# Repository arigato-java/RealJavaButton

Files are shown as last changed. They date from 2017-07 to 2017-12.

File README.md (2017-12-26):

# RealJavaButton v1

JavaButton on the real world.

* 対象年齢: 全年齢 (審査申請準備中)

## Examples

Front(ver 1.0):
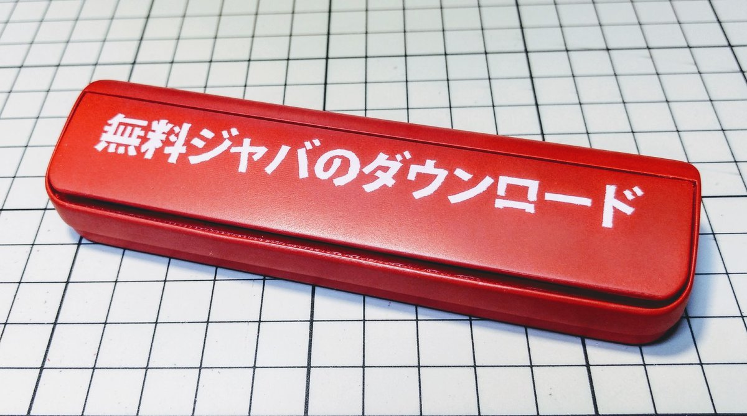
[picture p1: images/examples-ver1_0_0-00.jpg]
ver 1.0.0 front


Back(ver 1.0):
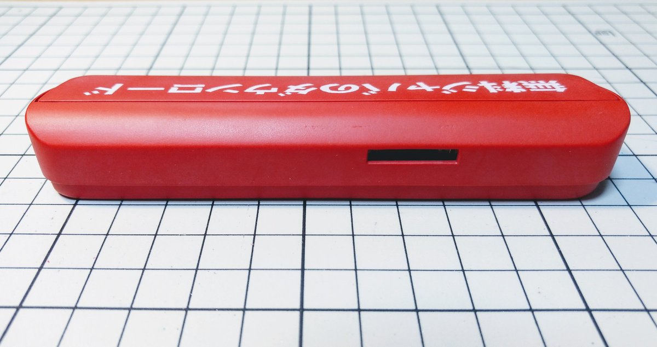
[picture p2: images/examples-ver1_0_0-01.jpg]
ver 1.0.0 back


Bottom(ver 1.0):
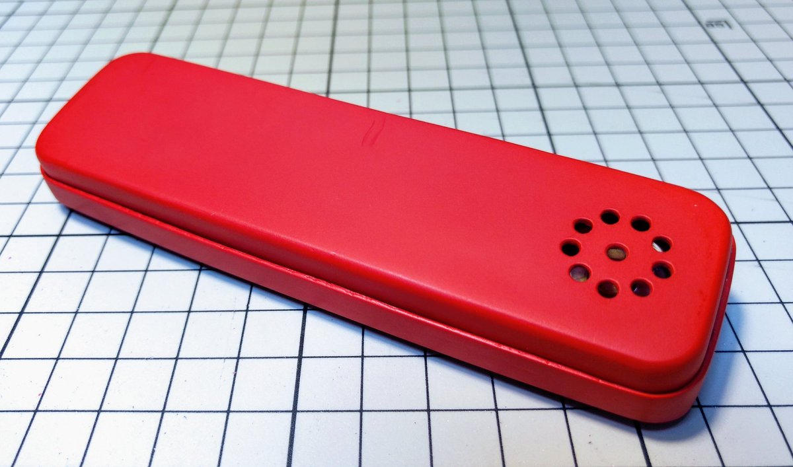
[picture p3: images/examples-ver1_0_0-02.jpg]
ver 1.0.0 bottom


Inside(ver 1.0):
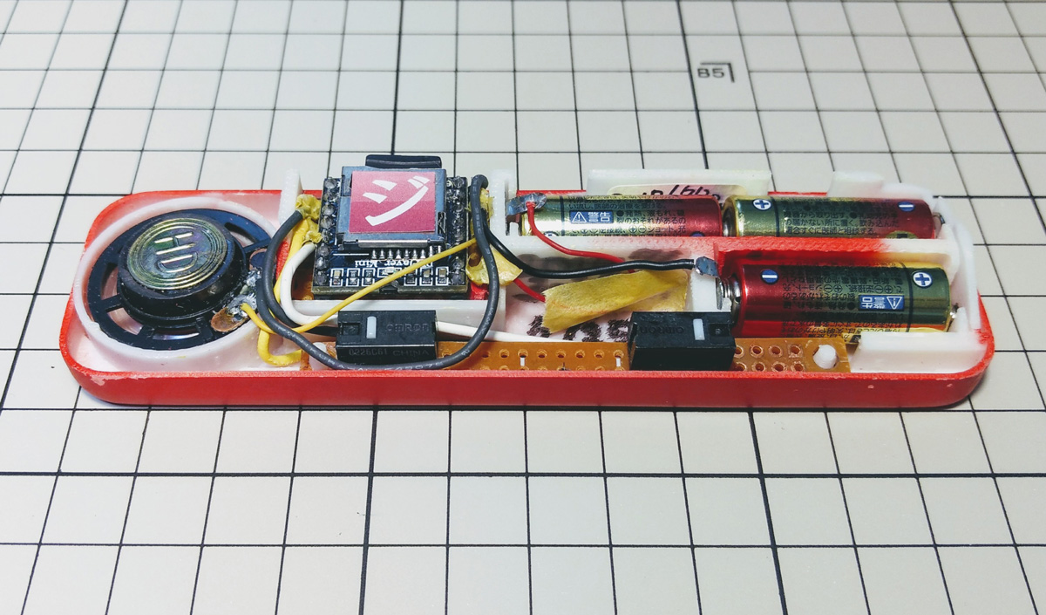
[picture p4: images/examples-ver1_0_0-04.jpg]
ver 1.0.0 inside


## Resources

* For 3D printing:
  * Top Cover Model([STL](./models/case-lid01.stl), [.f3d(Fusion360)](./models/case-lid01.f3d), [online](http://a360.co/2t33CEH))
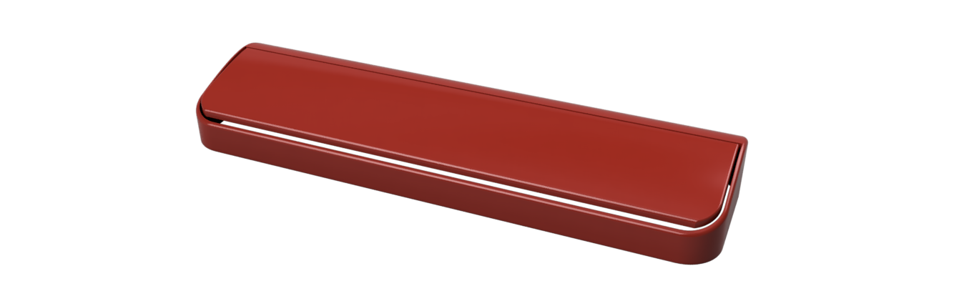
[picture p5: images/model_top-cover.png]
    
  * Bottom Model([STL](./models/case-bottom03.stl), [.f3d(Fusion360)](./models/case-bottom03.f3d), [online](http://a360.co/2umziJ7))
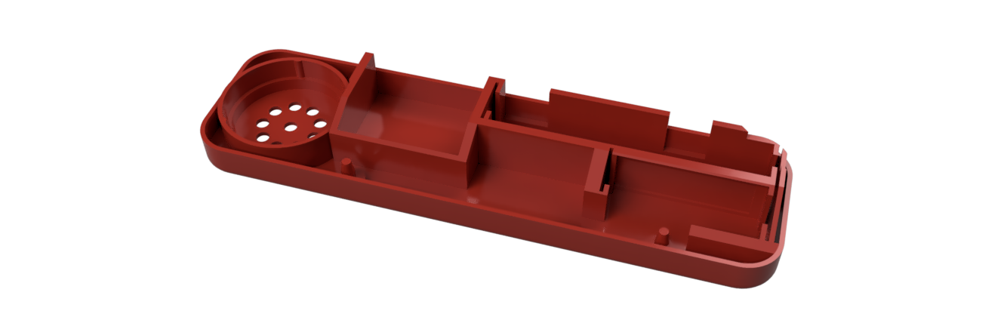
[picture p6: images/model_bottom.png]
    
  * Masking Sheet 印刷用:
    * [PDF](./images/javabutton_label00_170x225mm.pdf)
    * [Illustrator形式(.ai)](./images/javabutton_label00_170x225mm.ai)
    * [同 outline化済(.ai)](./images/javabutton_label00_170x225mm(outline).ai)

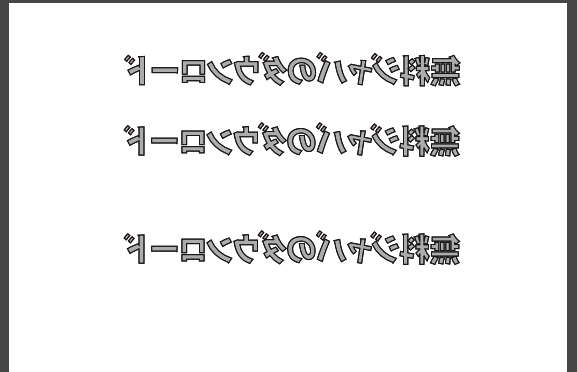
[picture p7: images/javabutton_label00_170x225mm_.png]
For Masking
    

    * (印刷には不要) 元データ:
    [Illustrator形式](./images/javabutton-string-only.ai)
    ([outline化済](./images/javabutton-string-only(outline).ai)))

## Bill of materials

部品リスト

* [FN-M16P Compatible Audio Module](https://www.amazon.co.jp/dp/B01D1D0E7Q/) x1
  ( [datasheet](http://www.trainelectronics.com/Arduino/MP3Sound/TalkingTemperature/FN-M16P%20Embedded%20MP3%20Audio%20Module%20Datasheet.pdf) )

* [OMRON D2FC Compatible Micro Switch](https://www.amazon.co.jp/dp/B00YM2Q178/) x2
* Cut universal board for Micro switch, about 71 x 8.5mm.(スイッチ取り付け用基盤をカットして用意) x1
* 8ohm 0.25w Speaker (⌀27mm)  x1
* Some short wires(短い導線いくつか)
* Battery contact(電池ボックス用金具) それぞれ幅 11mm 以内:
  * プラス側 金具 x1
  * マイナス側 金具 x1
  * プラスマイナス 金具 x1
* Battery: 1.5V N Cell(R1, 単5電池, 12x30.2mm)  x3

参考情報:

* 参考: Audio Module に関して、リンク先での購入は、2つのうち1つは動かない覚悟で。
* 参考: スピーカー取り付け用基板は、 ユニバーサル基盤から切り出した。
* 参考: スピーカーは、100均のおもちゃのピアノから流用。
* 参考: 電池ボックス用金具らは、100均のおもちゃから流用。
* 参考: 単5電池のプラマイは間違えやすく、ショートしやすいので注意。(要改善)

## Schematic

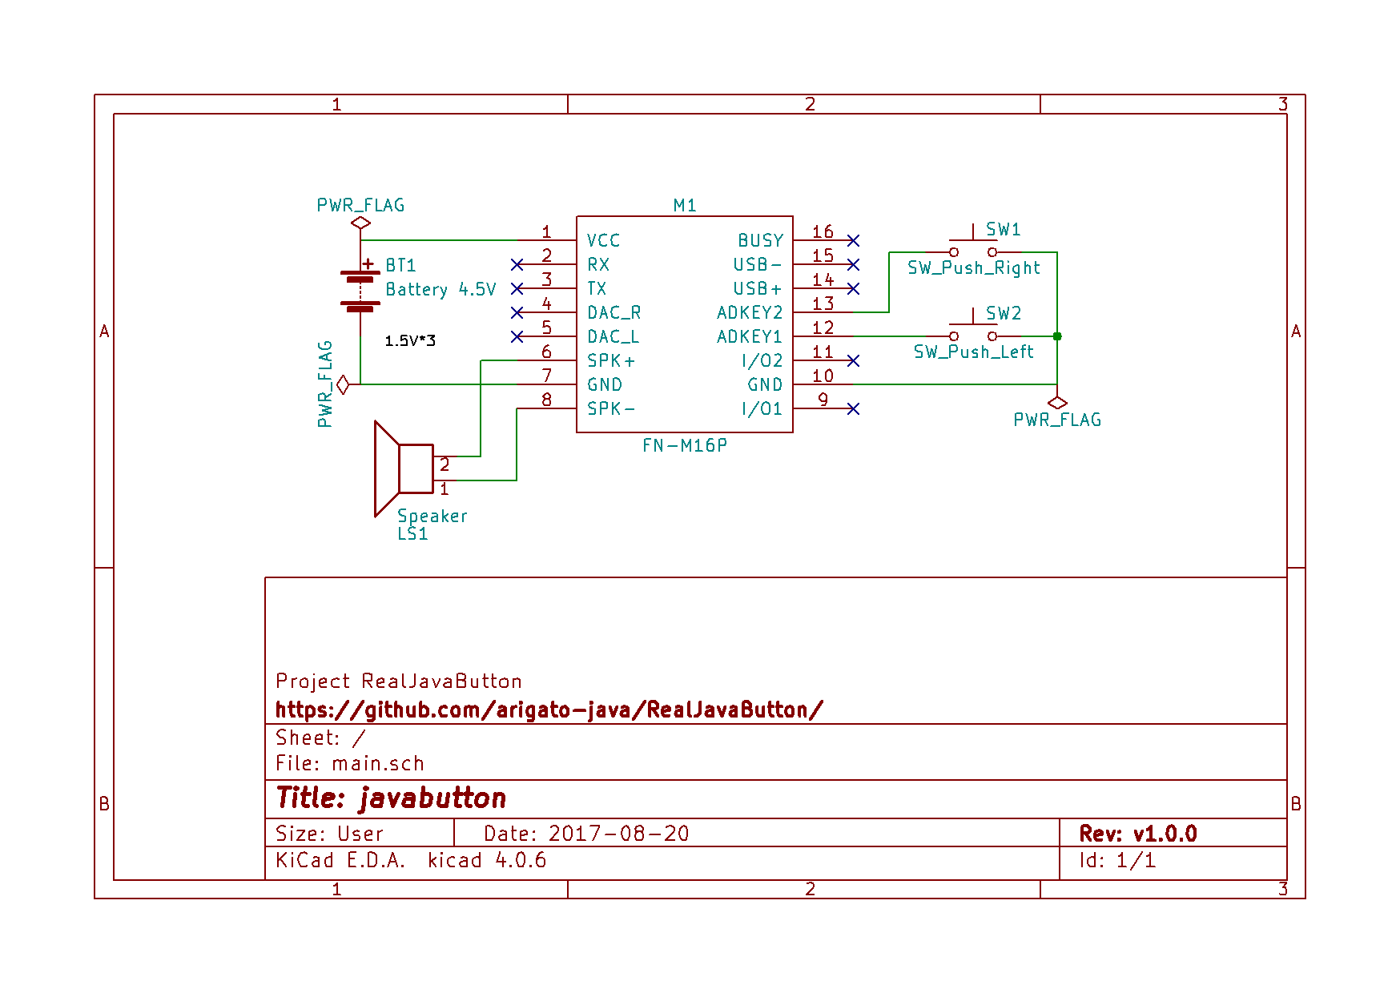
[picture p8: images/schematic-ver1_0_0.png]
ver 1.0.0 回路図


You can open `schematic/main.pro` using `KiCad` v4.x.x , if you want to see/edit those schematics.

## Confirmed environments(確認済み環境)

* For 3D printing
  * Printer: [Qidi Technology Dual Extruder Color 3D Printer / ABS / PLA 1.75mm デュアル押出/色](https://www.amazon.co.jp/dp/B01CRNV038/)
    * FDM Type(Fused deposition modelling, 熱溶解積層法)
    * Nozzle Diameter: ⌀0.4mm
    * Model: 3DF-QD-ABSYW
  * Filament : **ABS** (attached in the printer)
  * Slicer Software: MakerWare 2.4.1.24 (attached in the SD card, configured)
  * Platform Sheet: [3M platform Seat](https://www.amazon.co.jp/dp/B01M11XI4Y)
  * Configurations(see below)
* For painting:
  * 塗料等
    * サーフェサ: [ファインサーフェイサー(ピンク)](https://www.amazon.co.jp/dp/B00BBPUKDA)
    * 赤: [Mr.カラー キャラクターレッド(半光沢)](https://www.amazon.co.jp/dp/B0049FD5CC)
    * 白: [Mr.カラー スプレー S62 つや消しホワイト(つや消し)](https://www.amazon.co.jp/dp/B0049FBLFU)
    * 仕上げ材: [GSIクレオス Mr.トップコート(つや消し)](https://www.amazon.co.jp/dp/B0000WS12C)
  * パテ等
    * [ポリパテ](https://www.amazon.co.jp/dp/B000BMX1BM): 積層をなだらかにするため
    * [ラッカーパテ](https://www.amazon.co.jp/dp/B000R9N5VU): キズ埋めのため
  * [マスキングシール](https://www.amazon.co.jp/dp/B004WBC07Y):

      ジャバ文字の塗装用マスキングシート
  * デザインナイフ, ヘラ, 等々
  * ヤスリ: 320, 800, 1200(いずれも耐水性)
    * (あれば楽) [タイラー](https://www.amazon.co.jp/dp/B0026O9H6G)
      * 元のを剥がし、必要なヤスリを貼って使っている
    * 粉塵が出にくく、目詰まりしにくいため、水研ぎが楽
  * (あれば) 塗装ブース
* Software
  * CAD/CAM: **Autodesk Fusion360**

## Configurations to export from slicer (MakerWare)

Exaples:

* Top cover:

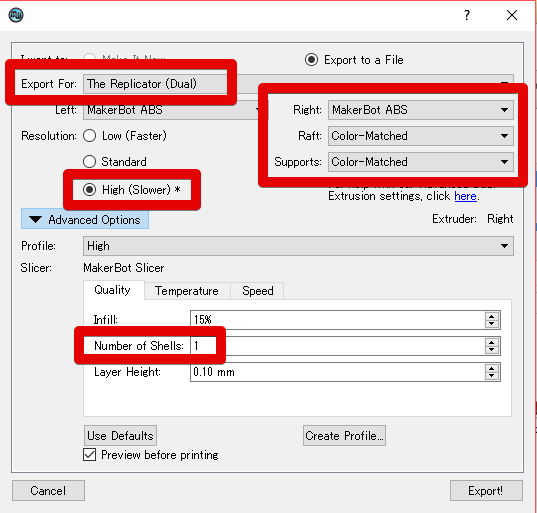
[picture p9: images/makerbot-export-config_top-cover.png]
上ブタ 設定
  

  Preview:

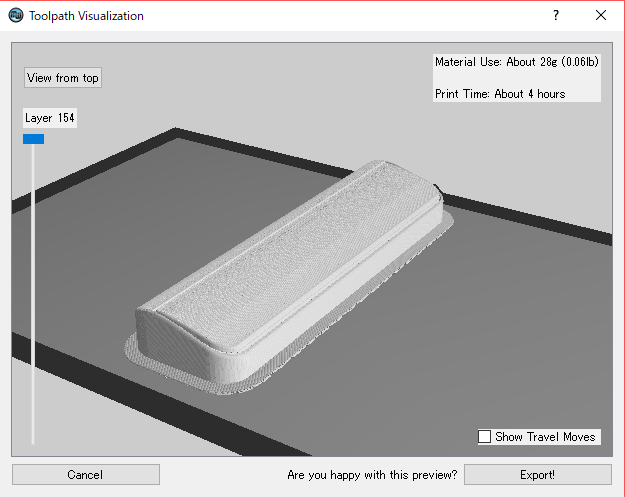
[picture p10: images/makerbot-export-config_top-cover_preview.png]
上ブタ 設定プレビュー
  

* Bottom case:

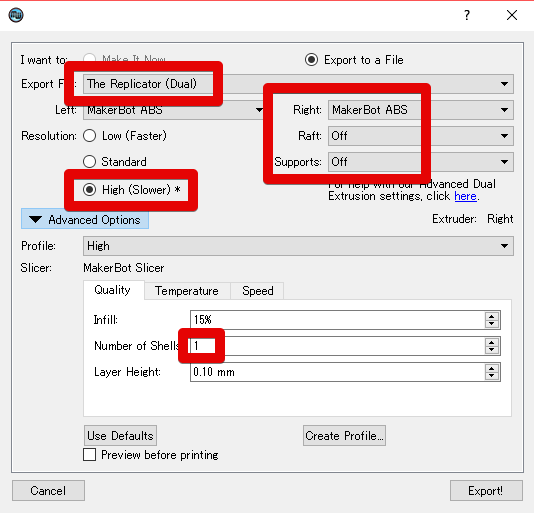
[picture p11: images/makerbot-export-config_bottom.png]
下ケース 設定
  

  Preview:

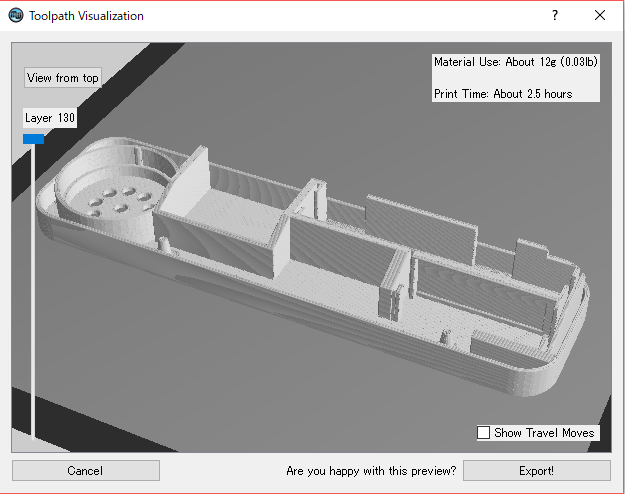
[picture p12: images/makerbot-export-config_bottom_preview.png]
下ケース 設定プレビュー
  

## Appendix: Examples of printing labels

文字塗装の例:

1. マスキングシートの裏に、文字列を印刷する。シートからマスキングを切り抜く。(データは前述)

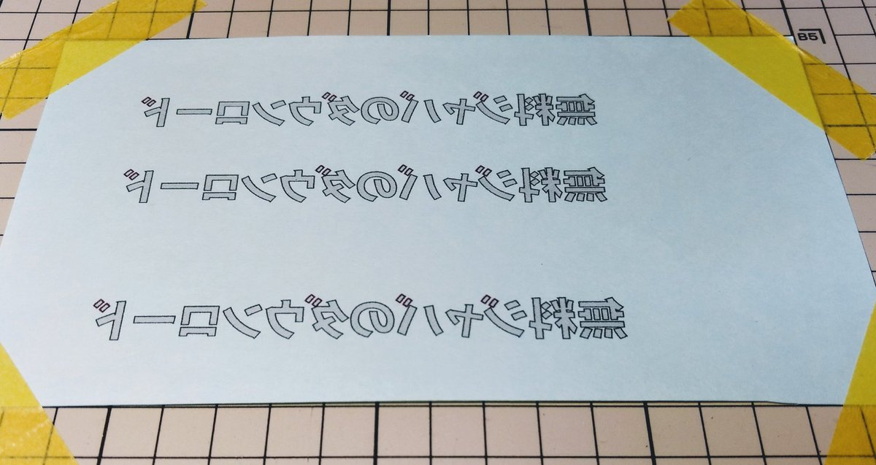
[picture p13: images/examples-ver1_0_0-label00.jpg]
    

1. 塗装済みのジャバボタンに貼る。スプレーされてもいいいように、マスキングシートの周りをマスキングする。(土台の利用は塗装を簡単にするため)

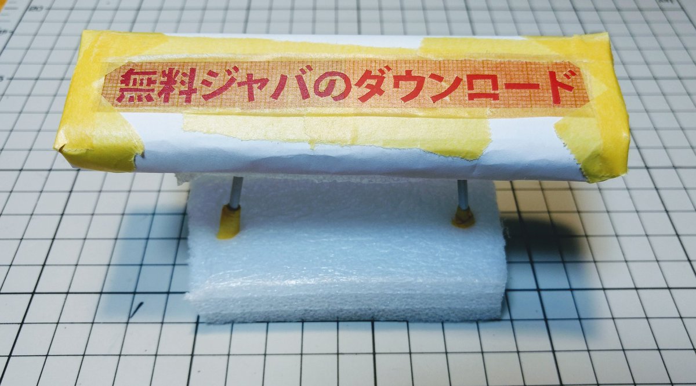
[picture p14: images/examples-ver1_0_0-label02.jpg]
    

1. 二度ほど白スプレーを吹き、乾いたのち仕上げ材を吹き、乾いたら出来上がり

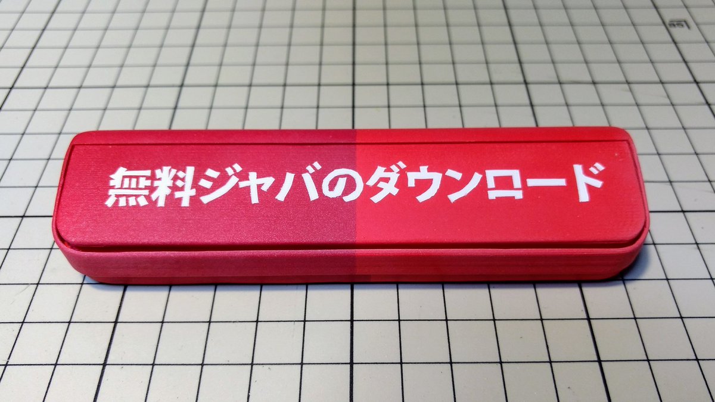
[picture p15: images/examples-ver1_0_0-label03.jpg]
    

    (※写真は試作中のものです)

## License

[Unlicense](./LICENSE)

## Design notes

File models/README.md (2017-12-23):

# About file format

* `*.stl`: General 3D format.
* `*.f3d`: For [Autodesk Fusion 360](https://www.autodesk.com/products/fusion-360/overview)

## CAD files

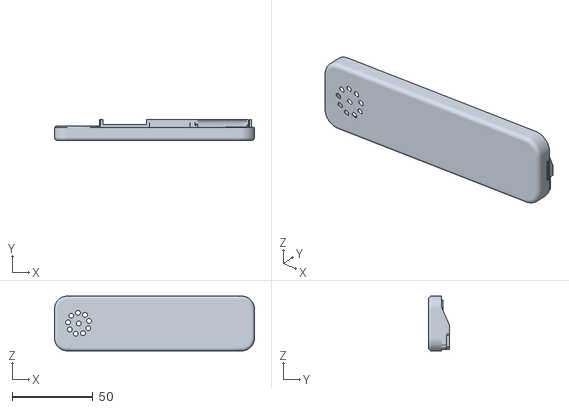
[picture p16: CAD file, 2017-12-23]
models/case-bottom03.stl
124.0 x 13.0 x 34.0

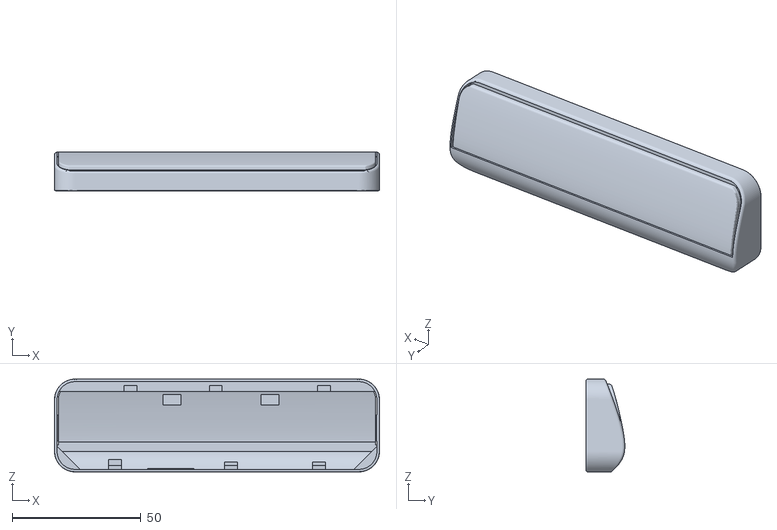
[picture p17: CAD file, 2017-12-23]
models/case-lid01.stl
126.0 x 15.0 x 36.0

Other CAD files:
models/case-bottom03.f3d
models/case-lid01.f3d

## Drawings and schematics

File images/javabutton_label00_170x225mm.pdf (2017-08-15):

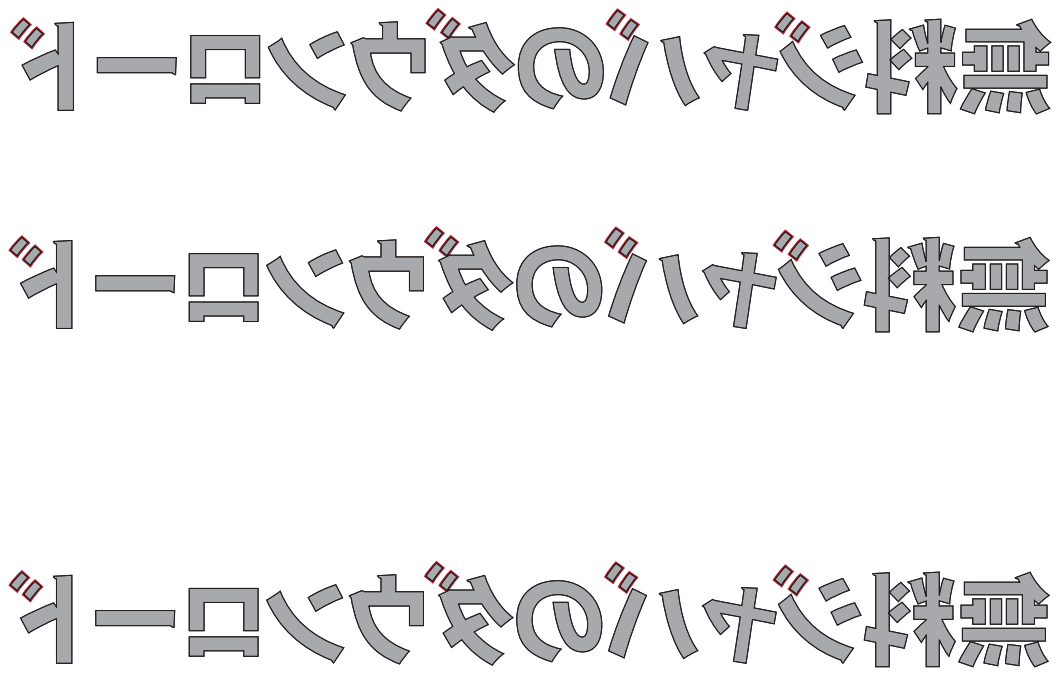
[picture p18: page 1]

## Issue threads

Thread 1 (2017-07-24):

上蓋の構造について

tomari, 2017-07-24:
素人の意見で申し訳ないのですが、上蓋の下半分が動くという構造は、見た目や造形の自由度の面で必ずしも有利と言えないと思っています。

上蓋を完全に一体にして（上蓋全体を押下可能にして）、継ぎ目が見えないような構造を作ることは難しいのですか？

tobynet, 2017-07-27:
元にしたおもちゃが、上ぶたの一部を押下する構造でした。
元は上ぶたは一体型でなかったのですが、一体にして今の形になっています。

現在はほんとに「作ってみた」状態でして、
上ぶた全体を押下可能にする案、アイデアはぜひ欲しいです。
(結果的に今回実現された左右を使ったクリック感は減るかもしれません)

ラフなスケッチなどあるとすごく参考になります。

tobynet, 2017-07-27:
ああっと、今、上ぶたに「切れ目」が入っていますが、そこをふさぎ、
マウスのような形状に、という案でしょうか。

tomari, 2017-07-27:
私の意図してる構造は、Apple Pro Mouseのような、上フタ全体がボタンというものです。
（これです：　https://www.flickr.com/photos/33585243@N04/3128121168 )

tobynet, 2017-07-29:
なるほど。 理解しました。これは目指す方向性と一致しますね。

tomari, 2017-11-19:
ジャバボタンライト：　光るジャバボタン (emissive Javabutton)、 仙人の意向を受け電飾の仕様が追加された。

tobynet, 2017-11-30:
Apple Pro Mouse を、秘密裏にジャックコーナーから入手いたしました。
これはすごい構造ですね。特許ものです。

tobynet, 2017-11-30:
自作キーボードの構造は参考になるやもしれません
ある意味、ジャバボタンというの上部構造は、細いキーボードにでかいキーキャップをかぶせた構造とも言えるわけです

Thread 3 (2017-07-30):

文字列の描写方法の模索

tobynet, 2017-07-30:
## サマリー

ジャバボ表面に文字列を入れる方法について、コスパの高い方法を模索したい。
見栄えよく、低コスト（「お金」と「労力」を減らす)を実現できないか。

## 試した方法の一覧

|                 | 手間 |再利用性|仕上り| 参考リンク |
|-----------------|:----:|:-----:|:----:|-----------|
|ステンシル        |  ◯  |  ◯   |  ×    | |
|マスキングシート   |  ×   | △    |  ◯    | |
|2色成型              | (未評価) | (未評価) | (未評価) | |

## 参考情報

* ステンシル
  * Pros:
    * 再現性は、3Dプリンタに依存
    * 再利用しやすい
  * Cons:
    * 塗装の出来はわるい(画像は後述)
      * 対象物と密着させにくく、塗料がはみ出る
    * 出力と調整の繰り返しが何度か必要。
  * 工程例:
    1. CADでデータを作成
    1. 3Dプリンタにて型を出力
    1. ナイフで型を調整
    1. 対象に貼り付け、塗料を塗る

* マスキングシート
  * Pros:
    * 塗装の出来はわるくない(画像は後述)
  * Cons:
    * 「無料ジャバのダウンロード」の切り抜きに、一時間程度の時間と集中を要する。
    * 再利用しにくい(2,3回が限度か)
    * 出力と調整の繰り返しが何度か必要。
  * 工程例:
    1. Illustlator でデータ作成
    1. インクジェットプリンタを使い、マスキングシートに印字
    1. デザインナイフでシートを切り抜く
    1. 対象にシートを貼り付け、塗料を塗る

* デュアル3Dプリンタによる二色成型:
  * (未評価)

## 参考画像

* ステンシル(?)での実装例
  1. 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
  1. 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
  1. 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
* マスキングシートでの実装例
  1. 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
  1. 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
  1. 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

* TODO: 二色成型

## 他

* 他によい案はないか
* 改善方法はないか

tomari, 2017-07-30:
キーボードでは、２色成形とよばれる方法が使われることがあります。
現在の3D プリンタのワークフローや精度に乗るかは不明ですが、再現性という面では期待が持てそうです。
http://www.yamashita-denki.co.jp/product/plastics/dm/dm02.html

tobynet, 2017-07-30:
ありがとうございます、いい案ですね。

環境さえ用意できれば、再現性の面で大きいのがよいですね。
塗装を各自でやるのは、たいへんですので。。。

* **前提:** 塗装なし
* **データ:** 2色用の3Dデータを用意
* **3Dプリンタ:** デュアルで出力が可能なもの
　* **素材(フィラメント):** 赤白を用意

幸いうちはデュアルの機種なので、赤白のフィラメントを用意できれば試すことができます。

設計が必要なのと、ワークフローが変わるため、今回のプロトタイプ以降に試してみたいです。

tomari, 2017-07-30:
その後ジャバ社の事務所でブレストをやっていました。その中で、インクジェット用の透明なステッカーシートを用いて文字を貼ってしまうというアイデアが出て、これは一考に値するかと思います。

tobynet, 2017-07-30:
シールいいですね。

表面を滑らかにしさえすれば、貼って終わりにできます。

tobynet, 2017-07-30:
現行の家庭用インクジェットプリンタは白色を出力できないため、
（原作に忠実に再現するならば）白いステッカーなどで代用する必要があることが判明いたしました。

tobynet, 2017-08-17:
パーツ分離による簡易化の方向[1] を検討中です。

[1] デュアルなプリンタでなくとも、それぞれ出力し、組み合わせればそれなりに見える方向

tobynet, 2017-08-30:
途中経過です。
赤、白、別々に出力して、組み合わせたものです。

合成後

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

ラベル(の図)

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

フタのみ

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

tomari, 2017-08-30:
最高です。これだと、押しすぎて文字の塗装が剥がれてしまうことがないわけで、大幅な改善になっていると思います。

tobynet, 2017-12-25:
v2.x 系をアップしました。
https://github.com/arigato-java/RealJavaButton/tree/v2.x

v2.x 系には、改良後のものもあるのですが、githubにはアップしてません。周辺デザイナさんのウケが良くなかったもので。(実は、改良後のものの方が、組立しやすかったり、より文字が浮き出て見えたりはします)

## 以下、(アップされてない)改良後のもの:

* Fusion360の最新版へのリンク: http://a360.co/2l34Xsz
* 画像:
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

tobynet, 2017-12-25:
イシュータイトルの目的はかなったので、いったん close します。

Closed 2017-12-25.

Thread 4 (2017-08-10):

自走式ジャバボタン

tomari, 2017-08-10:
ジャバボタンが四輪駆動で自走するようにする。自動運転技術の応用も視野に入れる。

tobynet, 2017-09-10:
参考資料:

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 (via <https://twitter.com/Akkiesoft/status/906305137248833536>)

動画: <https://twitter.com/Akkiesoft/status/906308859710410752>

Ejectコマンドユーザー会なる謎の組織が暗躍しているようです

tomari, 2017-09-10:
Software Design 2017年9月号 にeject コマンドハックとして記事載ってるのを見ました。

tomari, 2017-09-10:
関連研究として IBMの TJBot というのがあります。少し参考になりそうな感じがします https://ibmtjbot.github.io/

tomari, 2018-07-31:
EMドライブなど、最先端の駆動技術を取り入れたい

tobynet, 2018-07-31:
EMドライブは、大気圏内でも実用にたるものなのでしょうか
https://ja.wikipedia.org/wiki/EM%E3%83%89%E3%83%A9%E3%82%A4%E3%83%96

tomari, 2018-08-03:
そういった点も含めて、ジャバボタンという実用的な応用で採用すれば話題性が期待できると考えてます。

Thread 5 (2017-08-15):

推奨出力環境の明示

tomari, 2017-08-15:
以下情報をリドミに明示してほしい

* プリンタ名称、リビジョン等
* 樹脂タイプ
* ほか出力設定
* ソフトウェア環境

tobynet, 2017-08-15:
了解です。ジャバ連の侵攻が開始されるまでには、用意をいたします。

tobynet, 2017-08-15:
部品リスト、回路図以外を記載しました。

書きなぐったので読みずらいです。 整える必要ありか。

tomari, 2017-08-16:
上フタと下ケースのToolpath VIsualizationのエビデンスが逆になってませんか？
ラフトの状況からの推定です。

tobynet, 2017-08-17:
Fix it . ( https://github.com/arigato-java/RealJavaButton/compare/1ca8b36...38f2cba  )

Thanks @tomar .

tobynet, 2017-08-17:
問題なければ、一旦クローズします

Closed 2017-08-17.

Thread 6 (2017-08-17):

TGS出展

tomari, 2017-08-17:
新型ゲーム機「ジャバボタン」をTGSで発表する

tobynet, 2017-08-30:
「TGS前にリークされた新型ジャバボタン」として以下の写真が出回っています。
当組としての対処が必要ではないでしょうか。

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

tomari, 2017-08-30:
概ね、中国向けローカライゼーションを外注した大連の会社からのリークですね。連絡して警告しておきます。

tomari, 2017-10-14:
お疲れ様でした。

tomari, 2017-10-14:
予定が合わなかった人のために、現地のジャバボタンブースの様子を添付します

tobynet, 2017-10-21:
TGS発表どうでしたか。また聞かせてください。お疲れ様でした!

Closed 2017-10-14.

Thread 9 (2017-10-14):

ジャバボタンミニ

tomari, 2017-10-14:
機能を削ぎ落とし、サイズを小さくした派生商品を限定数出荷する。

tomari, 2017-10-19:
ジャバボタンミニはポケットにいつも入れておいてジャバにならないサイズ。
音を鳴らす機能は無し（本来のジャバボタンも音が出る機能はない）。
とにかく製造を低コストで外注。

tobynet, 2017-10-21:
ミニジャバボ製造に関しまして。DMM.make を利用するのはどうでしょうか。

・カラーが実現可能
・外注可能
　(ただし製造コストは量産品のようにはいかない)
・データ納品可能

カラーの場合の選択肢：

・石膏（フルカラー化） https://make.dmm.com/print/material/#1
・フルカラープラスチック https://make.dmm.com/print/material/#20

※ 一度、知人と石膏（ホワイト）を利用したことはあるのですが、直接オーダーはしてないので、
いまいちど試す必要はあります。

頒布は、同クリエイターズマーケットでできるとよいのかもしれません。

tobynet, 2017-12-23:
https://github.com/matobaa/OneKeyboardWithDigispark

リンク先にある100円均一のLEDボタンに、赤字白色のシールを貼り、「ジャバボタン・ミニ」と言いはる案を思いつきました。
リンク先にはマイコンが乗ってますが、載せません。
（あくまで案ですが）

tomari, 2018-03-14:
ジャバボタンの中からジャバボタンが出てくる、матрёшкаのようなものはお土産として適していそうです。
いざというときは、適切な大きさのジャバボタンとして使えるわけですし。

tomari, 2018-03-21:
3D プリンタで、鋳型のようなものを作ることはできるのでしょうか。冷凍庫に入れておけば、氷のジャバボタン像ができるようなものは、売れると思います。

tobynet, 2018-03-21:
もしやるなら、プロトタイプ、モデルを作るまでになるかと思います。
うちの3Dプリンタでは、削る前のプロトタイプを作る精度と速度で精一杯です。

100均なんか製氷皿は、バキューム成形なんですかね？

積層型の安価なプリンタで、コップを作られている方を発見しました。 食用を考えると、プリンタでの出力は不安になるのは分かりありますね。。
http://3dprinterand.me/make-a-toothpaste-cup-with-a-3d-printer/

tobynet, 2018-03-21:
おお、プロトタイピング用途だと、個人でもバキューム成形できるんですね。
https://tech-blog.cerevo.com/adventcalendar2016/advent18/

tobynet, 2018-03-21:
バキューム成形、ふつうにジャバボタンの複製に使えるのでは。。。

Youtube:
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

tomari, 2018-03-31:
H.M.S. Real Artists Ship という船の模型をオプションで装着可能にする

tobynet, 2018-04-02:
19世紀当時、イギリスのジョブズがこう言ったという。「(石炭船でもよいから) 戦って初めて戦艦となる」と。

tobynet, 2018-04-02:
下町ジャバボは、2038年のジャバリンピックでは使われなかったと聞いています。

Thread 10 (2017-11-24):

ジャバボタンの枕カバー

tomari, 2017-11-24:
抱き枕カバーでも良いですが、枕カバーとジャバボタンは、トポロジが似ているので、容易に実現可能な気がします。

tobynet, 2017-11-24:
日常のジャバとして、よい案です。実にいいですね。

tobynet, 2017-11-24:
裏返すと、普通の紅いまくらになりカモフラージュも可能に

tobynet, 2017-11-24:
赤の布地に、白の印字が可能か。もしくは装飾できる業者がいるか。調査が必要ですね。
量産する必要はないので、オーダーメイドでもいいと思います。

tomari, 2017-11-24:
白の印字が、様々なところで障害になるようなら、企画の工夫で回避するのも手かもしれません。
例えば、「ナイトメアジャバボタン」として、色が反転したジャバボを本編に登場させておいて、それを作ったという格好にする、などです。

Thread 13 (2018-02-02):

電源問題の解決

tobynet, 2018-02-02:
現在、電池は いわゆる「単5」型1.5V 3個を使っている。
割高な上、入手もしずらい。この問題を解決したい。

案:

* 有線化
  * ACアダプタとその端子から 5V を供給。
　例: https://twitter.com/toby_net/status/958012314313093120
  * microUSB端子をつきそこから 5V を供給。
   * おそらく可能
* Li-Po バッテリー内蔵:
　4.7～5V用を用意し、付ける。
  * 充電制御用回路は手元にあるが、バッテリーはまだない
* カメラやラジコン用バッテリーを降圧して使う。
  * 製品かされており、充電器等もうられている。

Pros.
* いずれも、かなりの小型化が見込める

Cons.
* Li-Poバッテリー:  取り扱いによっては燃える(素人工作では怖い)
  * カメララジコンのバッテリーは、裸(？)の Li-Po よりマシと考えております。

tomari, 2018-02-02:
モバイルバッテリーには、それなりに小型のものがいくつかあります。
microUSB給電にすることで、安価なモバイルバッテリーの応用・改造ができるようになります。

tobynet, 2018-02-07:
思い切って microUSB 給電にすれば、市販のモバイルバッテリーを使えますね。ナイスアイデアだ。。

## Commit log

2017-08-17 Add examples of printing labels
2017-08-19 Add list of materials
2017-08-19 Add schematics
    [main.kicad_pcb, main.sch]
2017-08-20 部品リストの表現を一般的なものに変更
2017-08-20 CERO審査結果を追加
2017-08-20 まだ申請準備中でしたね
2017-12-23 Upload models (ver 1.0)
    [case-bottom03.f3d, case-bottom03.stl, case-lid01.f3d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]
2017-12-23 Fix links of stl
